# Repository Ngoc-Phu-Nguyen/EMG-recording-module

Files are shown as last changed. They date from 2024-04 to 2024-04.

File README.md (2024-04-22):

# EMG-recording-module
Design for the hardware of EMG recording module  and 3D with cases||
Code for system: STM8S, bluetooth HC-05, EMG recording module || 
# Hardware of EMG recording module
The module use a system filter that enough to clean the signal input before going to ADC. The ADC have I2C interface and programmable gain. The I2C is useful for multiple devices if necessary, and the programmable gain use for auto adjustment function.


Fig1. Scheme of circuit 




Fig2. 3D view of circuit




Fig3. 3D view with cases



Fig4. The real one - this module includes two main parts: Transmitter and receiver. The transmitter includes: STM8S, battery, EMG recording and HC-05. The receiver includes: black pill STM32, HC-05. 



Fig 5. Result of signal EMG from the module - Signal is quite clean. There is almost no noise and interference. The sampling rate of signal is 3ms.

# Coding
Using the tool ST Visual Develop to program and debug for STM8S: setup: CLK, peripheral - I2C, UART,...

Using Arduino and tool Arduino IDE to program for HC-05 (AT command)

Using tool STM32CubeIDE to program and debug for SMT32: peripheral UART

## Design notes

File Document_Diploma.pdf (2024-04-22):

1

Министерство науки и высшего образования Российской Федерации Федеральное государственное автономное образовательное учреждение высшего образования
«Национальный исследовательский Томский политехнический университет»
Школа / филиал | ИШНКБ
Обеспечивающее подразделение | Отделение электронной инженерии
Направление подготовки / специальность | 12.03.04 Биотехнические системы и технологии
Образовательная программа (направленность (профиль)) | Биотехнические системы технологии

ОТЧЕТ

ПО УЧЕБНО-ИССЛЕДОВАТЕЛЬСКОЙ РАБОТЕ

Тема | Разработка автоматического усилителя модуля регистрации ЭМГ
Выполнил обучающийся | Нгуен.Н.Ф
Группа | 1Д01

_____________________

(Подпись обучающегося)

Дата сдачи работы «___» __________ 2024 г.

Проверил науч. руководитель _____________________________________________________

(Степень, звание, должность) | (Ф.И.О.)

Дата проверки____ __________ 2024 г.

Баллы (из 40) ___________

Допустить/не допустить к защите,

Подпись ___________
Отчет принял¹
________________________________________________________________
(Степень, звание, должность) | (Ф.И.О.)
Дата защиты _____ __________ 2024г.
Баллы (из 60) | ___________
Подпись | ___________

Итоговое решение: зачет/незачет, итоговые баллы (из 100) _________________

Томск 2024

1 Председатель комиссии по защите УИРС – руководитель ООП

2

УТВЕРЖДАЮ

Руководитель ООП

__________Е.Ю. Дикман

«___»_________2024 г.

ИНДИВИДУАЛЬНОЕ ЗАДАНИЕ

На учебно-исследовательскую работу

Тема учебно-исследовательской работы:

Разработка автоматического усилителя модуля регистрации ЭМГ

Перечень работ (заданий), подлежащих выполнению:

1. Разработка структурной схемы устройства
2. Разработка принципиальной схемы плата модуля регистрации ЭМГ
3. Разработка программы для микроконтроллера
4. Экспериментальные результаты

Научный руководитель

_____________________________________________ ____________________
(Должность) | (подпись) | (Ф. И. О.)

Задание принял к исполнению _____________ _________________________

(Подпись) | (Ф. И. О. обучающегося)
«___» _________ 2024

3

Оглавление

Разработка принципиальной схемы плата модуля регистрации ЭМГ....... 7

4

Введение

Разрабатываемое устройство главным образом направлено на

использование в сборе данных ЭМГ верхней конечности с целью

использования его для управления протезом руки.

Верхняя конечность включает в себя различные группы мышц, каждая

из которых проявляет различный диапазон амплитуды в сигналах

электромиографии (ЭМГ). Вместо использования ручной калибровки

усиления усилителя или фиксированного уровня усиления автоматическая

система регулировки усиления предоставляет более точное и практичное

решение для захвата различных диапазонов ЭМГ, характерных для различных

групп мышц. Этот автоматизированный подход не только повышает точность

мониторинга | активности | мышц, | но | также | обладает | значительной

универсальностью в многочисленных областях применения, включая

управление протезами. Возможность динамически адаптировать уровень

усиления сенсора для соответствия конкретным характеристикам ЭМГ

различных мышечных групп не только обеспечивает более точный сбор

данных, но также открывает перспективы для передовых приложений в

области протезирования, где точное и отзывчивое управление играет

ключевую | роль | в | улучшении | функциональности | и | интеграции

протезированных конечностей.

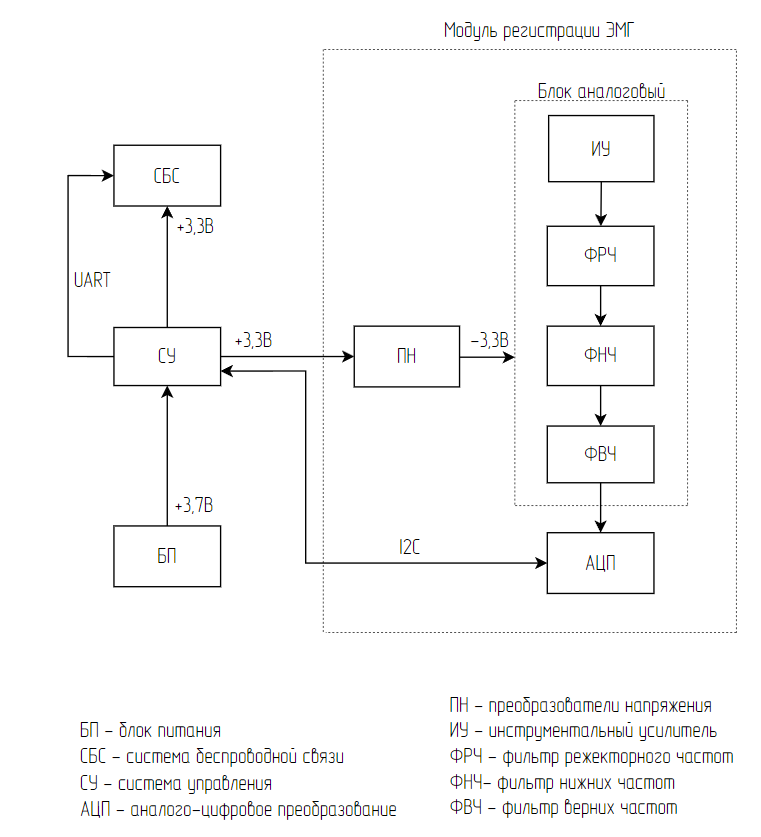
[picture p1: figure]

5

Разработка структурной схемы устройства

На | рисунке | 1 | представлена | структурная | схема | устройства

автоматического усилителя модуля регистрации электромиографии (ЭМГ).

Рисунок 1 – Структурная схема

6

Блок питания (БП) обеспечивает требуемым напряжением каждый

элемент схемы. В качестве источника будут выступать Li-ion аккумулятор. Для

стабилизации | и | получения | необходимого | напряжения | используется

преобразователя постоянного напряжения на 3.3 В.

Система управления (СУ) – обеспечивает взаимодействие и управление

всех | блоков, | устройства. | Для | реализации | данной | системы | будет

использоваться МК STM8S 103F3P6. Поскольку он оснащен необходимыми

интерфейсами: UART, I2C; достаточным количеством памяти и частоты.

Задача СУ будет заключаться в приеме и обработке данных от модуля

регистраиции ЭМГ , последующей отправки этих данных через СБС.

Система беспроводной связи (СБС) – беспроводная связь будет

обеспечивать контакт устройства с принимающей стороной (протезом,

ноутбуком…) для передачи данных. Будет использоваться модуль Bluetooth

HC-05, который простой в использовании, предназначенный для прозрачной

настройки беспроводного соединения. Из СУ будут передаваться собранные

данные от АЦП в СБС и отправляться принимающей стороне.

Регистрация модуля ЭМГ включает: ПН - Преобразователи напряжение

будет | подавать | отрицательное | напряжение | на | усилители. | ИН | -

Инструментальный усилитель будет принимать дифференциальный сигнал от

электрода и эффективно подавлять общий сигнал. Система фильтров включает

в себя ФРЧ - фильтр режекторного частот , ФНЧ - фильтр нижних частот, ФВЧ

- фильтр верних частот. Эти фильтры хорошо удаляют почти весь шум и

помехи. Кстати, через все фильтры сигнал будет усилен настолько, что его

можно | будет | прочитать. | АЦП | - | аналого-цифровое | преобразование

используется для преобразования аналогового сигнала в цифровой сигнал, и с

помощью интерфейса I2C MК может считывать этот цифровой сигнал.

7

Разработка принципиальной схемы плата модуля регистрации

ЭМГ

Инстументальный усилитель AD8221

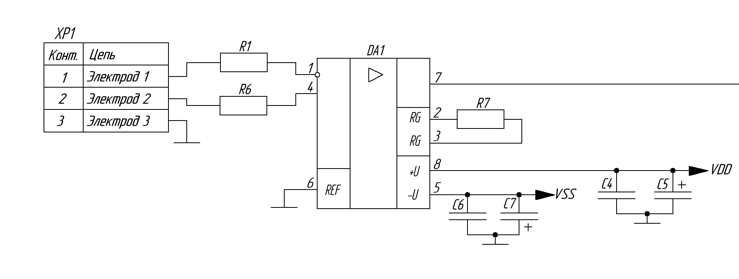
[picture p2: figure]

Рисунок 2 – Схема инструментального усилителя

Данный инструментальный усилитель питается он напряжения ±3.3 В,

для сглаживания более высокочастотных помех применяются конденсаторы

более низкой емкости С4, С5, С6, С7. Конденсатор керамический емкостью 0,1

мкФ (С4, С6) следует разместить рядом с каждым контактом питания,

танталовый конденсатор емкостью 10 мкФ (С5, С7) можно использовать

дальше от детали[1].

Резистор R1, R6 используется для ограничения тока при наличии

напряжения ESD. Следовательно, все компоненты будут защищены от

высотких тока.

Системый фильтр

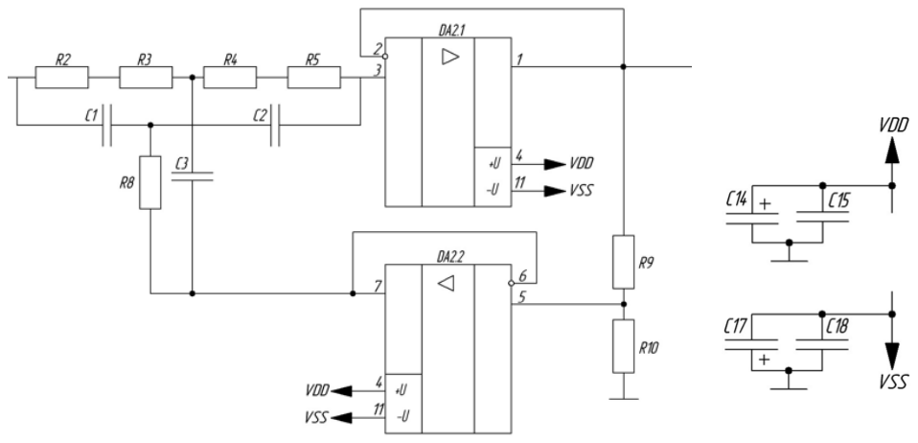
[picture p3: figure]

Рисунок 3 – Фильтр режекторного частот

8

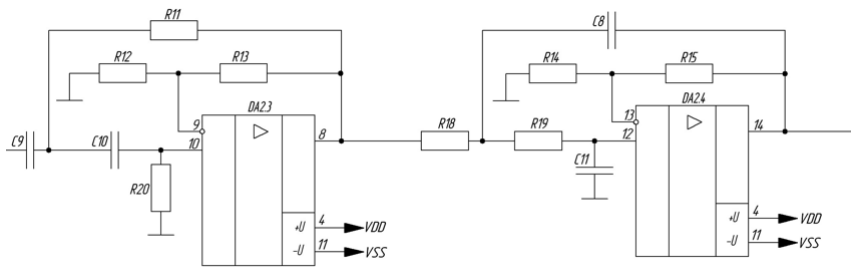
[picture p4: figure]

Рисунок 4 – Фильтр нижник и верних частот

Данные операционные усилители питаются он напряжения ±3.3 В, для

сглаживания более высокочастотных помех применяются конденсаторы более

низкой емкости С14, С15, С17, С18. Конденсатор керамический емкостью 0,1

мкФ (С15, С18) следует разместить рядом с каждым контактом питания,

танталовый конденсатор емкостью 2,2 мкФ (С14, С77) можно использовать

дальше от детали.

Преобразователи напряжения

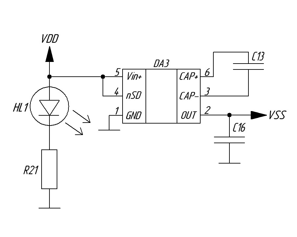
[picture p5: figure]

Рисунок 5 – Схема преобразователя напряжения

Чтобы | максимизировать | эффективность, | уменьшить | падение

выходного напряжения и пульсации напряжения[2], был использованы два

конденсатора Murata 10 мкФ с низким ESR.

Для индикации статуса получаемых напряжения используется

светодиод HL1 с ток ограничительным резистором (R21).

9

Аналого-цифровое преобразование

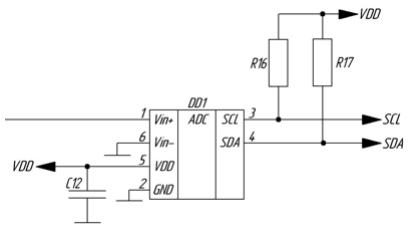
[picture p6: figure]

Рисунок 6 – Схема АЦП

Данный АЦП питается он напряжения 3.3 В, для сглаживания более

высокочастотных помех применяются керамический конденсатор более

низкой емкости С12. Конденсатор следует размещать как можно ближе к

выводу VDD (в пределах одного дюйма). Если схема приложения имеет

отдельные цифровые и аналоговые источники питания, VDD и VSS устройства

MCP3421 должны находиться в аналоговой плоскости [3].

Выводы SCL и SDA MCP3421 имеют конфигурации с открытым

стоком. Для этих контактов требуется подтягивающий резистор, как показано

на рисунке 6. Подтягивающий резистор обычно выбирается в диапазоне от 5

кОм до 10 кОм для стандартного и быстрого режимов [3].

Контактные выходы

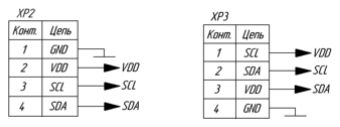
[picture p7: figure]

Рисунок 7 – Схема выходы

Выход предназначен для подключения к MCU через шину I2C, а также

доступен в случае использования нескольких модулей.

10

Разработка моделей печатных плат модуля регистрации ЭМГ

На рисунках 8-9 приводятся результаты разработки платы модуля

регистрации ЭМГ. Плата обеспечена монтажными отверстиями для крепления

её внутри корпуса. На плате имеются два отверстия диаметром 4 мм для пайки

электродами. Расположение | элементов было спроектировано с целью
минимизировать | шум | и | помехи. | Для | достижения | максимальной

эффективности, входной тракт инструментального усилителя выполнен

синхронным. Высокочастотный шум может исходить от цифровой части.

Поэтому аналоговая часть отделена от цифровой. Линия вывода сигнала

изолирована небольшими отверстиями, что гарантирует отсутствие помех.

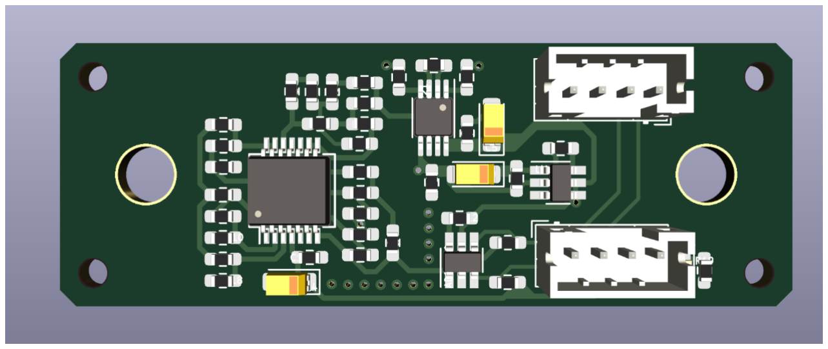
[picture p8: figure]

Рисунок 8 – Вид на верхнюю сторону платы

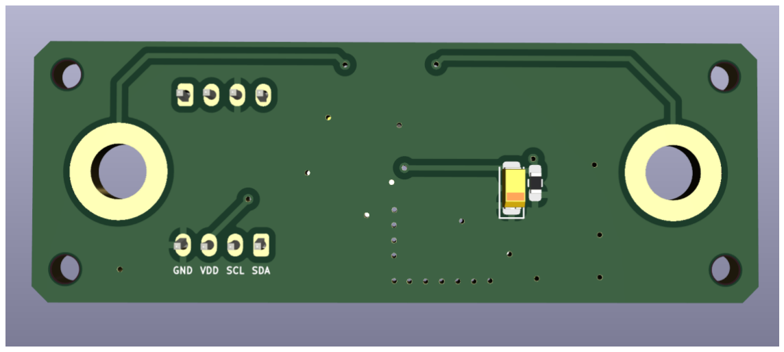
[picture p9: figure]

Рисунок 9 – Вид на нижнюю сторону платы

11

Разработка программы для микроконтроллер

Разработка библиотеки кода и I2C для MCP3421.

Конфигурация АЦП MCP3421 представлена на рисунке 10.

Библиотечный код для MCP3421 был написан на основе его конфигурации.

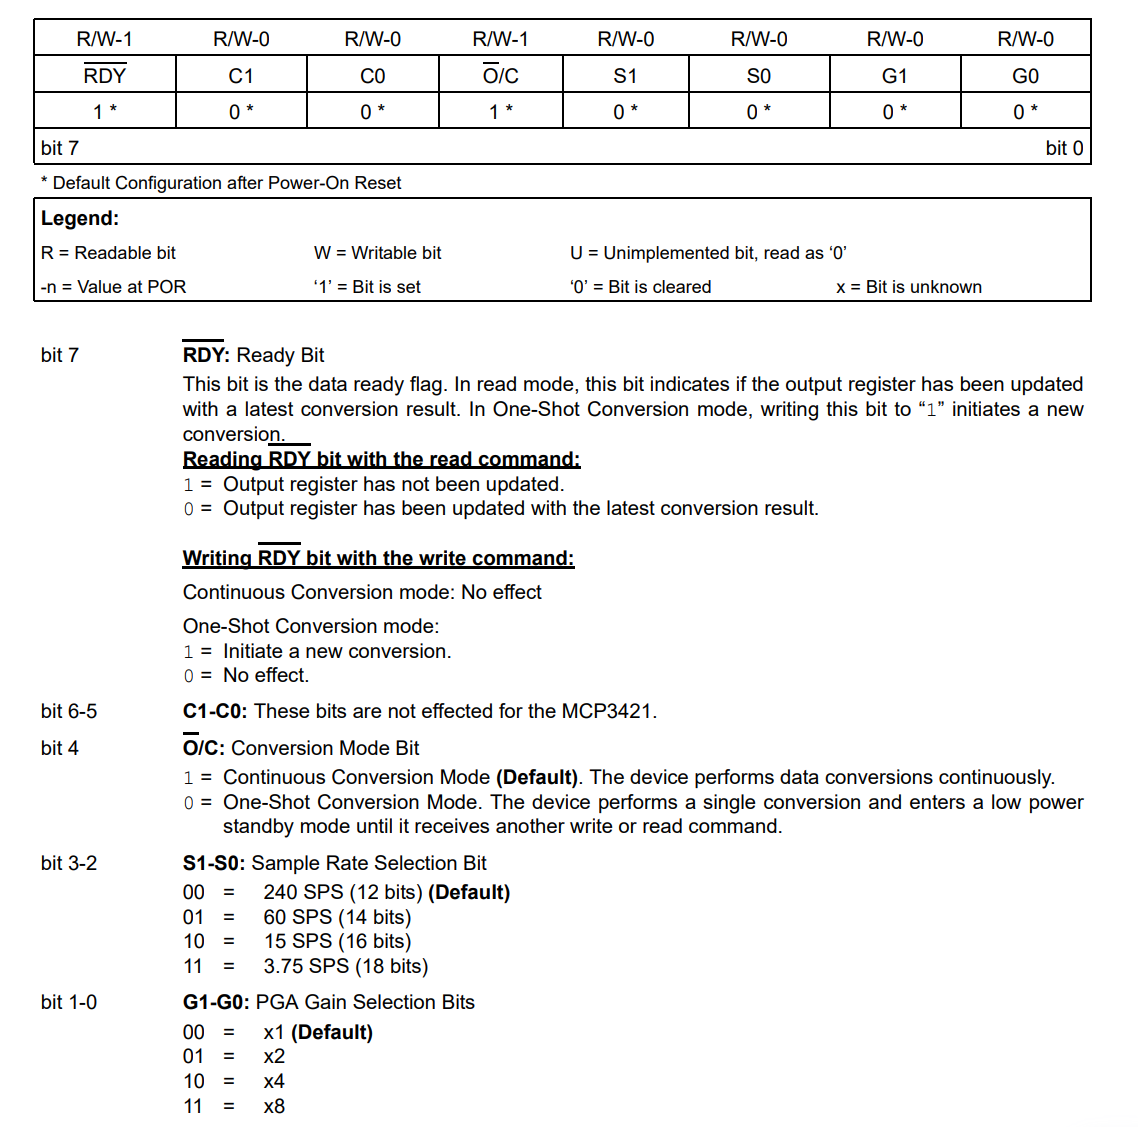
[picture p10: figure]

Рисунок 10 – Конфигурационный байт MPC3421

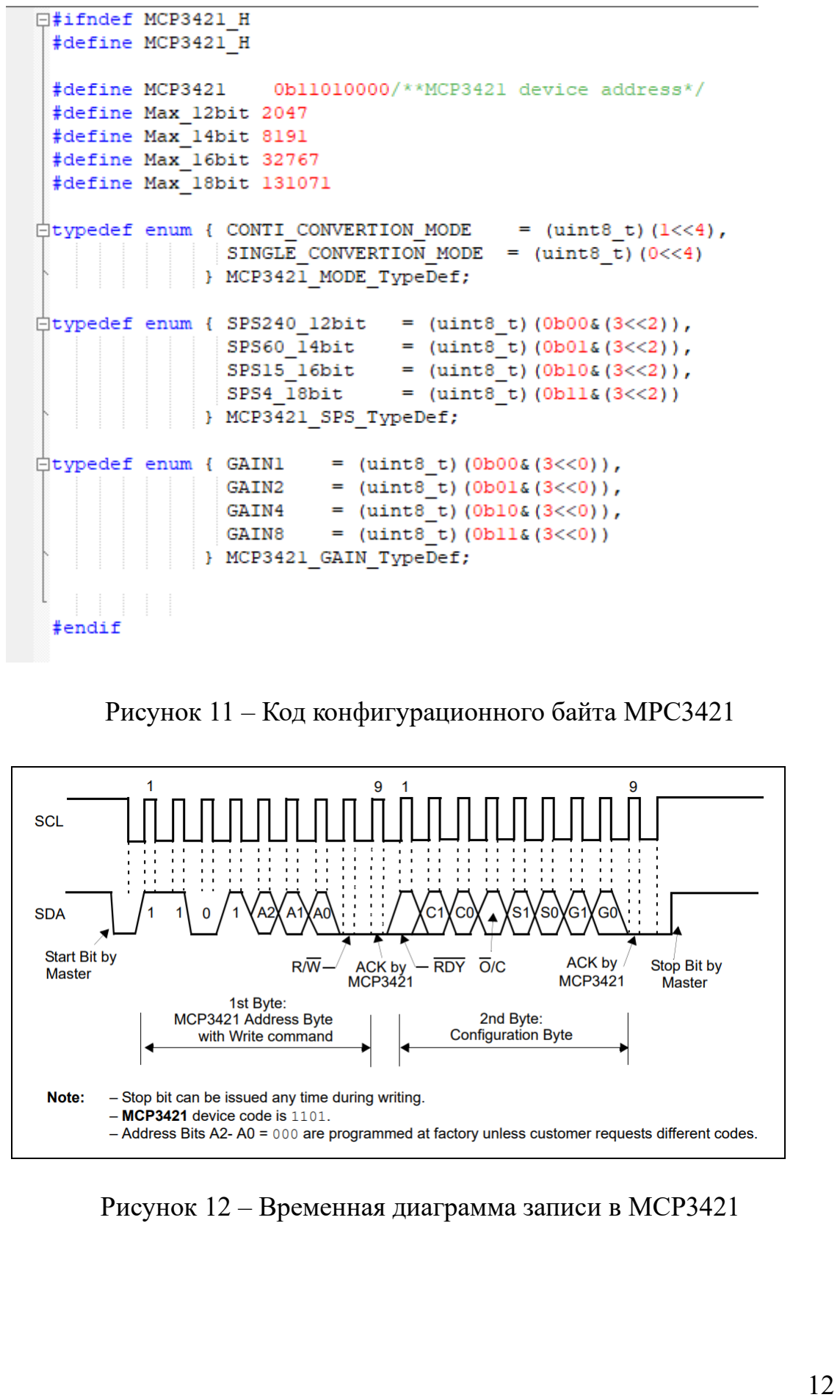
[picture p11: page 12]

12

Рисунок 11 – Код конфигурационного байта MPC3421

Рисунок 12 – Временная диаграмма записи в MCP3421

13

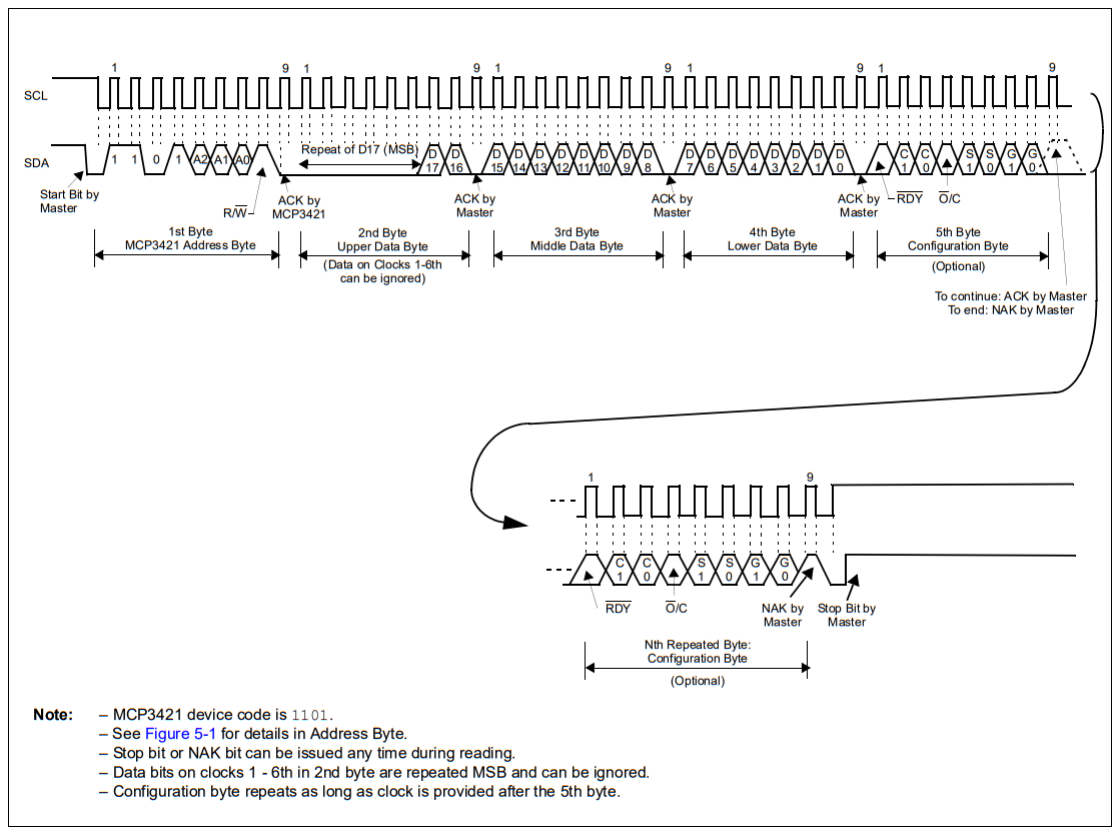
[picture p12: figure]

Рисунок 12 – Временная диаграмма чтения с MCP3421

Настройка для интерфейса I2C - это первый шаг, который должен быть

выполнен. Затем I2C запускается через бит START. Обратите внимание, что

также должен быть установлен бит ACK. Прерывание будет выполнено

немедленно, когда I2C запускается и устанавливается флаг SB. Внутри

обработчика прерываний первым делом отправляется адрес ведомого

устройства, чтобы проверить, совпадает ли он или нет. Если адрес совпадает,

процесс прерывания повторяется, поскольку установлен флаг ADDR. Затем

проверяется флаг TRA, чтобы определить, будет ли I2C в режиме чтения или

записи. В каждом режиме соответственно считывается или записывается

регистр DR. В конце процесса чтения или записи должен быть установлен бит

STOP, чтобы освободить шину перед переходом к новому общению.

На основе функционального описания I2C в таблице данных STM8S[5]

и временной диаграммы чтения/записи MCP3421 (рисунок 11,12) было

написано краткое описание, которое также используется для алгоритма

(рисунок 13).

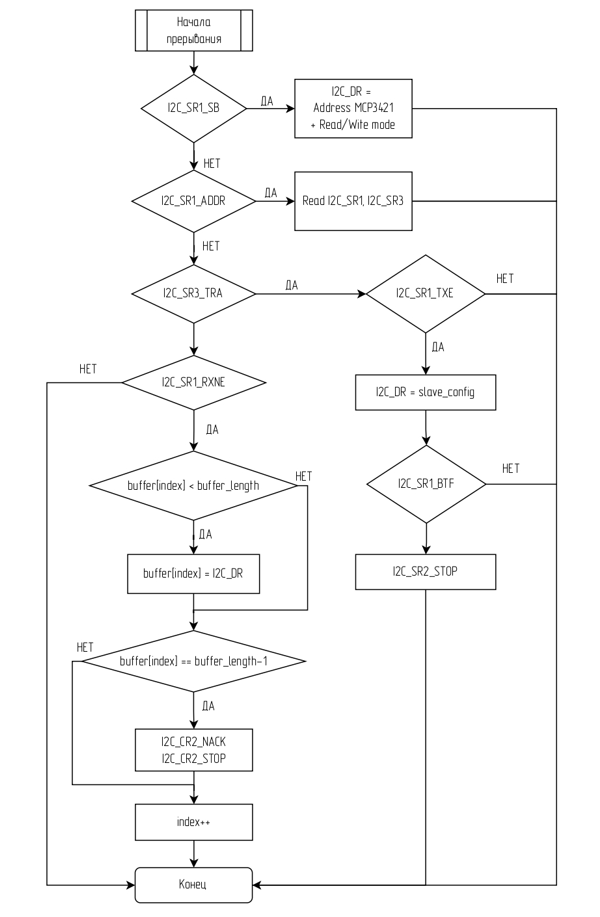
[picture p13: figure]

14

Рисунок 13 – Алгоритм прерывания I2C STM8S

15

Настройка для HC-05

Для взаимодействия с HC05-модулем используются AT-команды.

Интерфейсом для взаимодействия служит UART. Первоначальные настройки

HC05 модуля заключались в следующем [4]:

− Тестовая команда: AT

− Проверить адрес AT+ADDR

− Настроить UART(baud rate, stop bit, parity): AT+UART=9600,1,0

− Установить/проверить режим модуля (master): AT+ROLE=1

− Установить/проверить режим подключения (фиксированный адрес):

AT+CMODE=0

− Подключиться к подчиненному устройству: AT+BIND=xxxx,xx,xxxxxx

Чтобы включить режим AT для модуля HC-05, подключите вывод PIO11

к высокому уровню, используя скорость передачи данных 34800. Пример

показан на рисунке xx ниже.

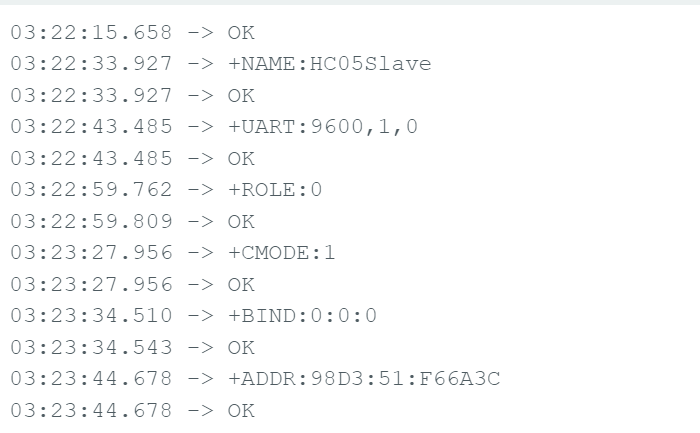
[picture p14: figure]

Рисунок 14 – Ответ от HC05 при использовании AT-команды

16

Фунция автоматического усиления

Как только значение будет получено от АЦП, будет запущен процесс

проверки, чтобы убедиться, что значение все еще находится в пределах

диапазона. Если выход за пределы диапазона достигнут, коэффициент

усиления АЦП снижается. Этот процесс повторяется до тех пор, пока не будет

достигнут минимальный коэффициент усиления. Алгоритм всей программы

показан на рисунке 15 ниже. Код программы указан в приложении Е.

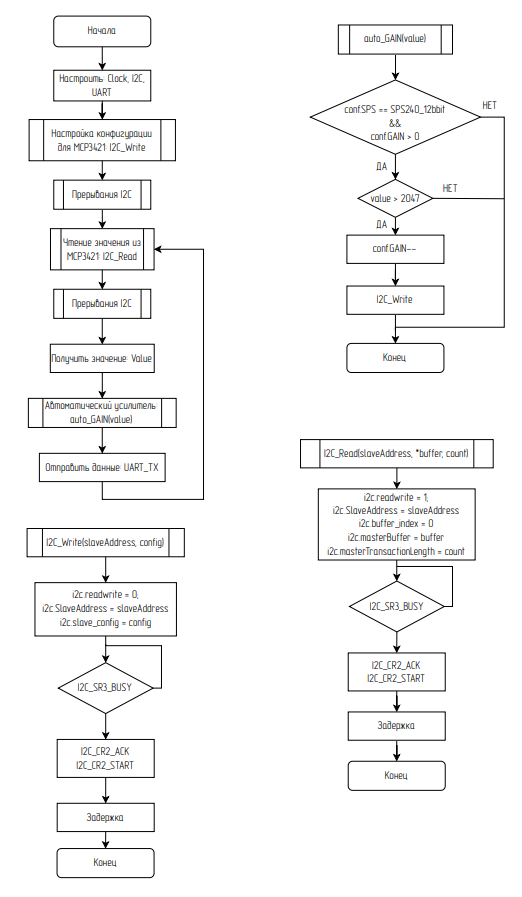
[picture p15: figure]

Рисунок 15 – Алгоритм всей программы

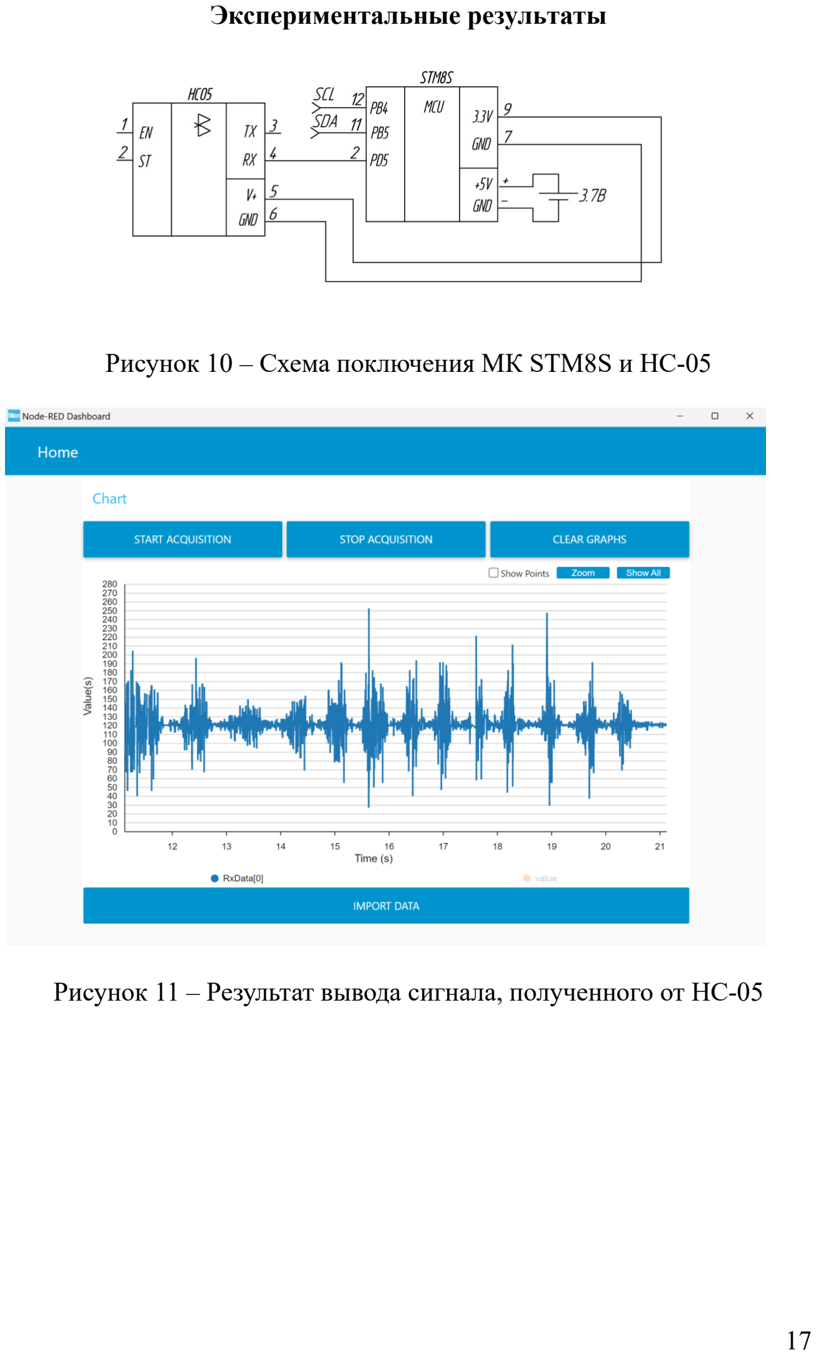
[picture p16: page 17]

17

Экспериментальные результаты

Рисунок 10 – Схема поключения МК STM8S и HC-05

Рисунок 11 – Результат вывода сигнала, полученного от HC-05

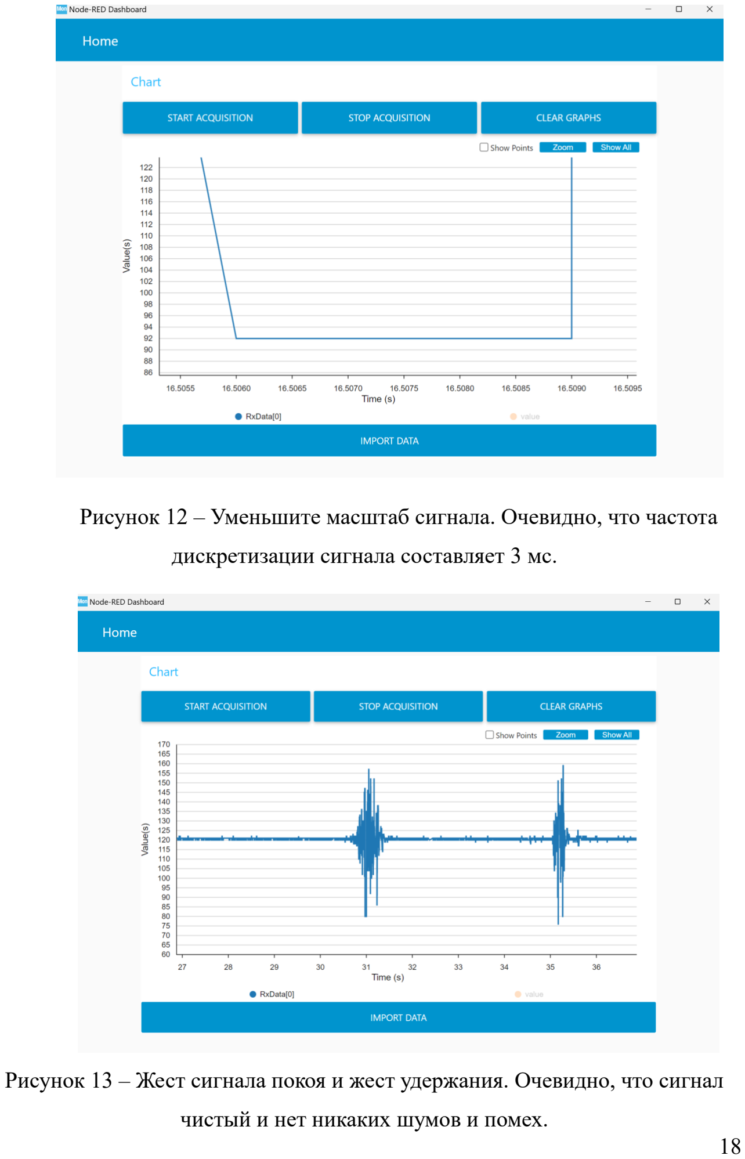
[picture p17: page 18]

18

Рисунок 12 – Уменьшите масштаб сигнала. Очевидно, что частота

дискретизации сигнала составляет 3 мс.

Рисунок 13 – Жест сигнала покоя и жест удержания. Очевидно, что сигнал

чистый и нет никаких шумов и помех.

19

Список литературы

1. Datasheet – AD8221, Инструментальный усилитель, [Электронный

ресурс] – Режим доступа: https://www.analog.com/media/en/technical-

documentation/data-sheets/ad8221.pdf (Дата обращения: 07.04.2024)

2. Datasheet – LM2664, Преобразователь напряжения с переключаемым
конденсатором, | [Электронный | ресурс] | – | Режим | доступа:

https://www.ti.com/lit/ds/symlink/lm2664.pdf?ts=1713246289404

(Дата обращения: 07.04.2024)

3. Datasheet – MCP3421, Цировный потенциометр, [Электронный

ресурс] – Режим доступа: https://www.analog.com/media/en/technical-

documentation/data-sheets/ad5259.pdf (https://www.analog.com/media/en/technical-documentation/data-sheets/ad5259.pdf) (Дата обращения: 07.04.2024)

4. Datasheet – HC-05, Модуль Bluetooth для последовательного порта,
[Электронный | ресурс] | – | Режим | доступа:

https://components101.com/sites/default/files/component_datasheet/HC

-05%20Datasheet.pdf ( Дата обращения: 07.04.2024)

5. Reference manual – STM8S Series and STM8AF Series 8-bit
microcontroller, | [Электронный | ресурс] | – | Режим | доступа:
https://www.st.com/content/st_com/en.html | (Дата | обращения:

07.04.2024)

20

Приложение А

Модуль регистрации ЭМГ

Спецификация

ФЮРА.942519.001

21

Приложение Б

Модуль регистрации ЭМГ

Схема электрическая принципиальная

ФЮРА.942519.001 ПЭ3

22

Приложение В

Модуль регистрации ЭМГ

Сборочный чертеж платы

ФЮРА.942519.002.СБ

23

Приложение Г

Модуль регистрации ЭМГ

Печатная плата

ФЮРА.942519.003

24

Приложение Д

Модуль регистрации ЭМГ

Перечень элементов

ФЮРА.942519.004 ПЭ

25

Приложение Е

Модуль регистрации ЭМГ

Код микроконтроллера

Код main.c

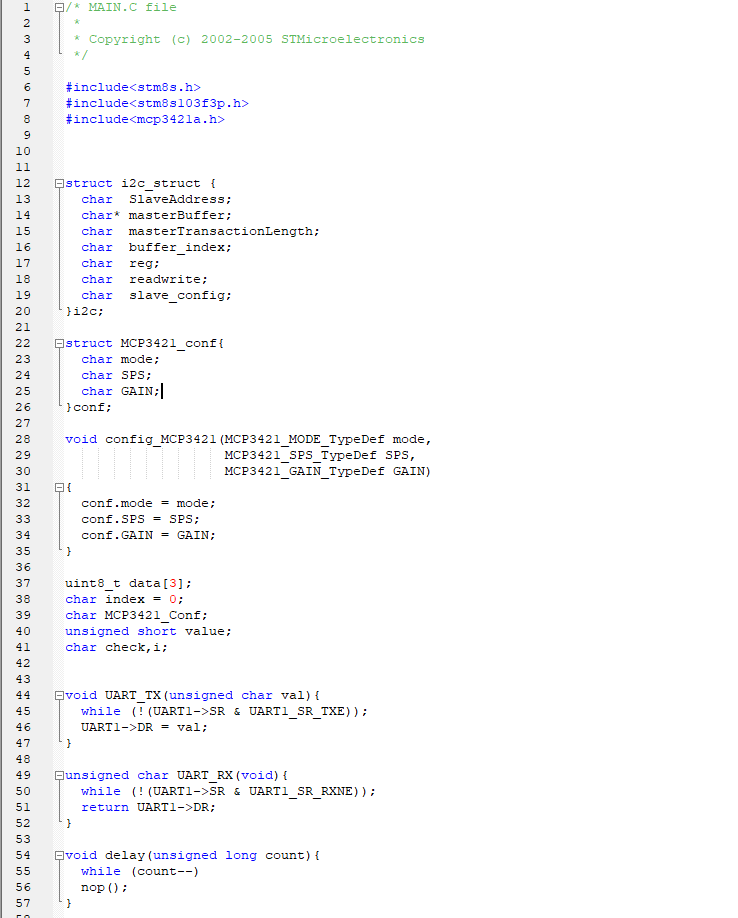
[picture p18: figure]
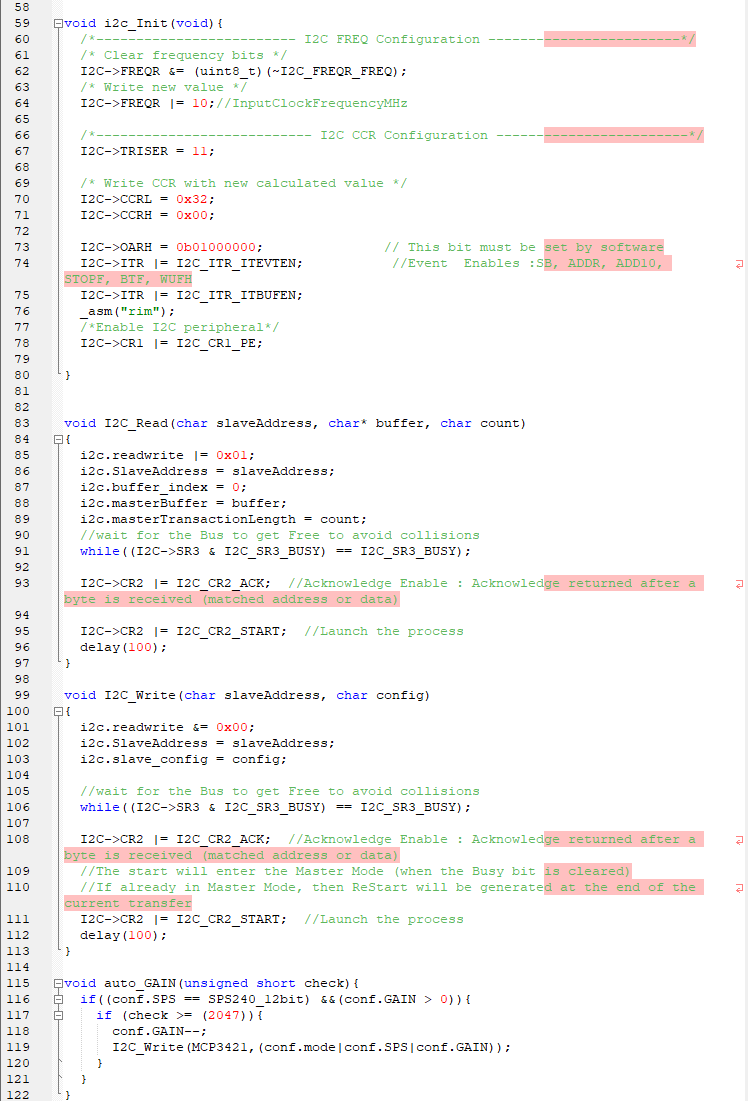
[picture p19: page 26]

26

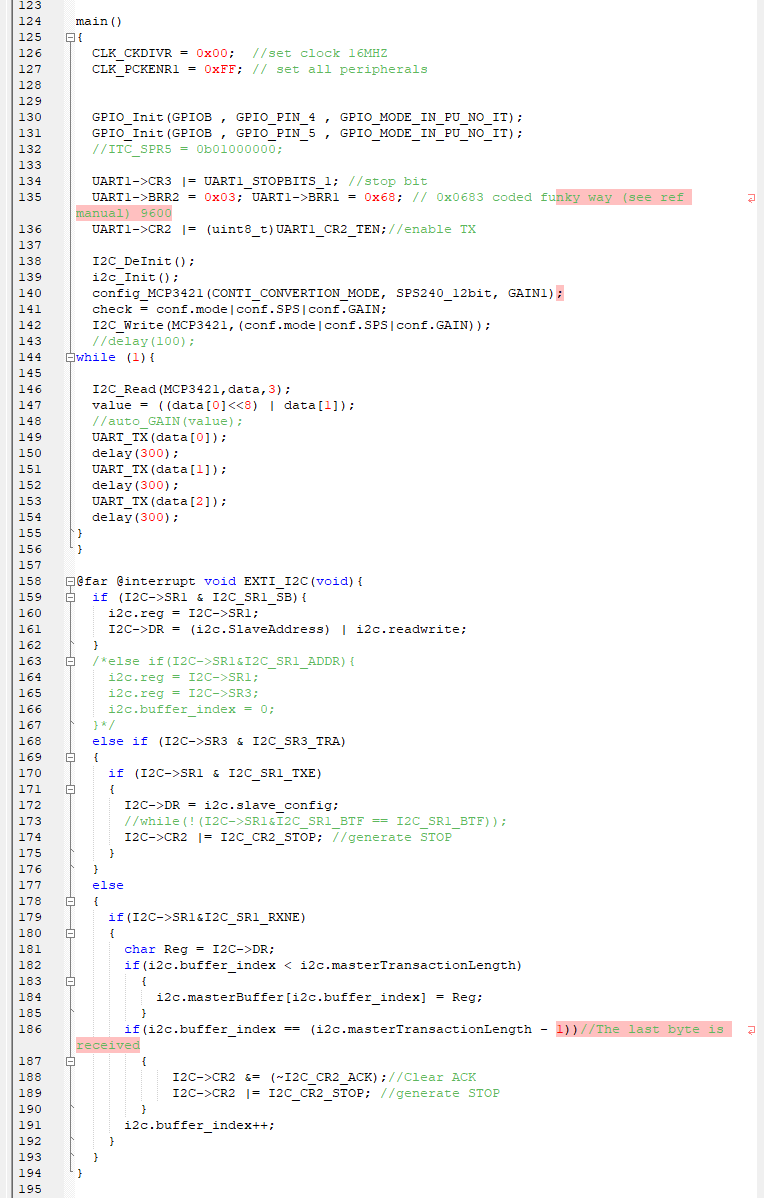
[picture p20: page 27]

27

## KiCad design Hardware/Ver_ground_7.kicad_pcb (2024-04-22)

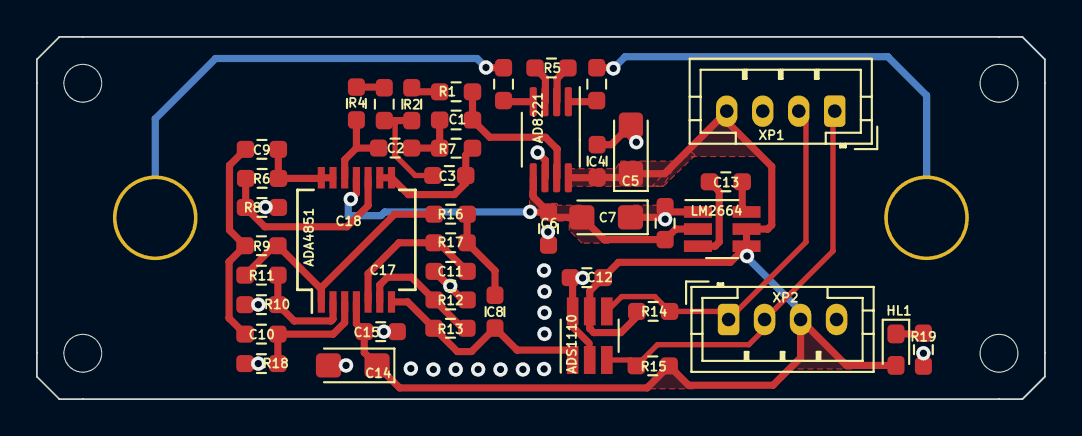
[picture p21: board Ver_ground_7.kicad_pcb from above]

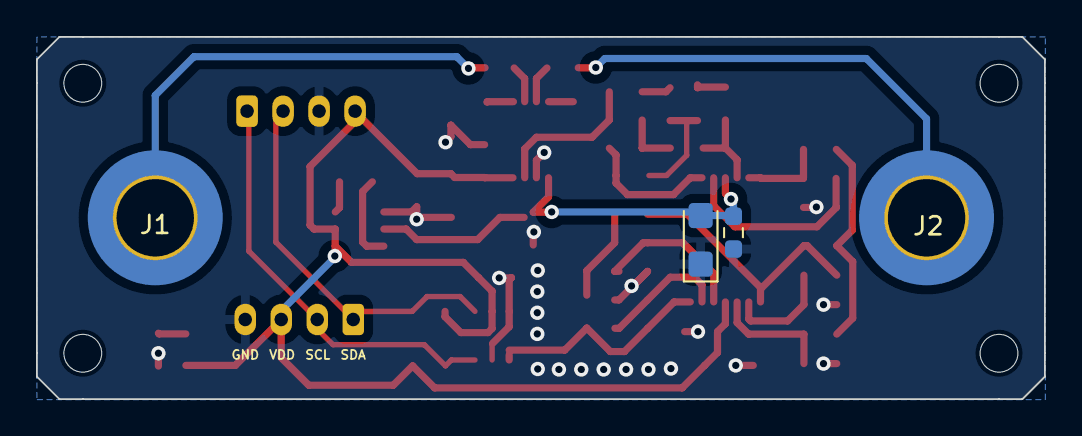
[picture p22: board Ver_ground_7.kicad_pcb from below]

Board: 2 copper layers, 56.0 x 20.1 mm, 52 parts (4 on the bottom side), 31 nets.

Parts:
C1, C2, C4, C6, C12: 0.1u; R_0603_1608Metric_Pad0.98x0.95mm_HandSolder
C3: 0.2u; R_0603_1608Metric_Pad0.98x0.95mm_HandSolder
C5, C7: 10u; CP_EIA-3216-18_Kemet-A
C8, C11: 3300p; R_0603_1608Metric_Pad0.98x0.95mm_HandSolder
C9, C10: 1u; R_0603_1608Metric_Pad0.98x0.95mm_HandSolder
C13, C16: 10u; R_0603_1608Metric_Pad0.98x0.95mm_HandSolder
C14, C17: 2.2u; CP_EIA-3216-18_Kemet-A
C15, C18: 0.01u; R_0603_1608Metric_Pad0.98x0.95mm_HandSolder
H1, H2, H3, H4: MountingHole; MountingHole_2.1mm
J1, J2: Conn_01x01_Pin; MountingHole_4.3mm_M4_DIN965_Pad_TopOnly
J3, J4: Conn_01x04_Pin; JST_PH_B4B-PH-K_1x04_P2.00mm_Vertical
LED1: IR26-21C_L110_TR8; LED_0603_1608Metric_Pad1.05x0.95mm_HandSolder
R1, R2, R3, R4, R7, R9, R18: 16k; R_0603_1608Metric_Pad0.98x0.95mm_HandSolder
R5, R6, R19: 1k; R_0603_1608Metric_Pad0.98x0.95mm_HandSolder
R8: 3.9k; R_0603_1608Metric_Pad0.98x0.95mm_HandSolder
R10, R12, R14, R15: 10k; R_0603_1608Metric_Pad0.98x0.95mm_HandSolder
R11, R13: 5.6k; R_0603_1608Metric_Pad0.98x0.95mm_HandSolder
R16, R17, R20, R21: 100k; R_0603_1608Metric_Pad0.98x0.95mm_HandSolder
U1: AD8221; MSOP-8_3x3mm_P0.65mm
U2: ADA4851; SSOP-14_5.3x6.2mm_P0.65mm
U3: LM2664; SOT-23-6_Handsoldering
U4: MCP3421; SOT-23-6_Handsoldering

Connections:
GNDA: C4.1, C5.2, C6.2, C7.1, C11.1, C12.1, C14.2, C15.1, C16.1, C17.1, C18.2, J3.3, J4.4, R8.1, R10.1, R12.2, R18.1, R19.1, U1.6 (Ref), U3.1 (GND), U4.2 (GND), U4.6 (VIN-)
unnamed: C1.1, R1.1, U1.7
unnamed: C1.2, C2.1, R7.2
unnamed: C3.2, R2.1, R3.2
unnamed: C8.2, R16.2, R17.1
unnamed: C9.2, C10.1, R9.1
unnamed: J1.1, R20.1
unnamed: J2.1, R21.1
unnamed: LED1.1 (K), R19.2
unnamed: R1.2, R2.2
unnamed: R3.1, R4.1
unnamed: R5.1, U1.2 (Rg)
unnamed: R5.2, U1.3 (Rg)
unnamed: R9.2, R11.2, R16.1, U2.1
unnamed: R21.2, U1.4 (+)
unnamed: R20.2, U1.1 (-)
unnamed: C10.2, R18.2, U2.3 (+)
unnamed: R10.2, R11.1, U2.2 (-)
unnamed: C11.2, R17.2, U2.5 (+)
unnamed: R12.1, R13.1, U2.6 (-)
unnamed: R6.1, R8.2, U2.10 (+)
unnamed: C3.1, R7.1, U2.8, U2.9 (-)
unnamed: C2.2, R4.2, U2.12 (+)
unnamed: C9.1, R6.2, U2.13 (-), U2.14
unnamed: C13.1, U3.6 (CAP+)
unnamed: C13.2, U3.3 (CAP-)
Out: C8.1, R13.2, U2.7, U4.1 (VIN+)
SCL: J3.1, J4.2, R15.1, U4.3 (SCL)
SDA: J3.2, J4.1, R14.1, U4.4 (SDA)
VDDA: C4.2, C5.1, C12.2, C14.1, C15.2, J3.4, J4.3, LED1.2 (A), R14.2, R15.2, U1.8 (Vs+), U2.4 (V+), U3.4 (nSD), U3.5 (V+), U4.5 (VDD)
VSSA: C6.1, C7.2, C16.2, C17.2, C18.1, U1.5 (Vs-), U2.11 (V-), U3.2 (OUT)

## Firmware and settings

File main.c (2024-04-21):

/* MAIN.C file
 * 
 * Copyright (c) 2002-2005 STMicroelectronics
 */

#include<stm8s.h>
#include<stm8s103f3p.h>
#include<mcp3421a.h>



struct i2c_struct {
	char	SlaveAddress;
	char*	masterBuffer;
	char	masterTransactionLength;
	char	buffer_index;
	char  reg;
	char	readwrite;
	char  slave_config;
}i2c;

struct MCP3421_conf{
	char mode;
	char SPS;
	char GAIN;
}conf;

void config_MCP3421(MCP3421_MODE_TypeDef mode,
										MCP3421_SPS_TypeDef SPS, 
										MCP3421_GAIN_TypeDef GAIN)
{
	conf.mode = mode;
	conf.SPS = SPS;
	conf.GAIN = GAIN;
}

uint8_t data[3];
char index = 0;
char MCP3421_Conf;
unsigned short value;
char check,i;


void UART_TX(unsigned char val){
	while (!(UART1->SR & UART1_SR_TXE));
	UART1->DR = val;
}

unsigned char UART_RX(void){
	while (!(UART1->SR & UART1_SR_RXNE));
	return UART1->DR;
}

void delay(unsigned long count){
	while (count--)
	nop();
}

void i2c_Init(void){
  /*------------------------- I2C FREQ Configuration ------------------------*/
  /* Clear frequency bits */
  I2C->FREQR &= (uint8_t)(~I2C_FREQR_FREQ);
  /* Write new value */
  I2C->FREQR |= 10;//InputClockFrequencyMHz
	
  /*--------------------------- I2C CCR Configuration ------------------------*/
	I2C->TRISER = 11;

	/* Write CCR with new calculated value */
  I2C->CCRL = 0x32;
  I2C->CCRH = 0x00;
	
	I2C->OARH = 0b01000000;               // This bit must be set by software
	I2C->ITR |= I2C_ITR_ITEVTEN;           //Event  Enables :SB, ADDR, ADD10, STOPF, BTF, WUFH
	I2C->ITR |= I2C_ITR_ITBUFEN; 
	_asm("rim");
	/*Enable I2C peripheral*/
	I2C->CR1 |= I2C_CR1_PE;
	
}


void I2C_Read(char slaveAddress, char* buffer, char count)
{
	i2c.readwrite |= 0x01;
	i2c.SlaveAddress = slaveAddress;
	i2c.buffer_index = 0;
	i2c.masterBuffer = buffer;
	i2c.masterTransactionLength = count;	
	//wait for the Bus to get Free to avoid collisions
	while((I2C->SR3 & I2C_SR3_BUSY) == I2C_SR3_BUSY);
	
	I2C->CR2 |= I2C_CR2_ACK;	//Acknowledge Enable : Acknowledge returned after a byte is received (matched address or data)

	I2C->CR2 |= I2C_CR2_START;	//Launch the process
	delay(100);
}

void I2C_Write(char slaveAddress, char config)
{
	i2c.readwrite &= 0x00;
	i2c.SlaveAddress = slaveAddress;
	i2c.slave_config = config;
	
	//wait for the Bus to get Free to avoid collisions
	while((I2C->SR3 & I2C_SR3_BUSY) == I2C_SR3_BUSY);
	
	I2C->CR2 |= I2C_CR2_ACK;	//Acknowledge Enable : Acknowledge returned after a byte is received (matched address or data)
	//The start will enter the Master Mode (when the Busy bit is cleared)
	//If already in Master Mode, then ReStart will be generated at the end of the current transfer
	I2C->CR2 |= I2C_CR2_START;	//Launch the process
	delay(100);
}

void auto_GAIN(unsigned short check){
	if((conf.SPS == SPS240_12bit) &&(conf.GAIN > 0)){
		if (check >= (2047)){
			conf.GAIN--;
			I2C_Write(MCP3421,(conf.mode|conf.SPS|conf.GAIN));
		}
	}
}

main()
{
	CLK_CKDIVR = 0x00;  //set clock 16MHZ
	CLK_PCKENR1 = 0xFF; // set all peripherals
	

	GPIO_Init(GPIOB , GPIO_PIN_4 , GPIO_MODE_IN_PU_NO_IT);   
	GPIO_Init(GPIOB , GPIO_PIN_5 , GPIO_MODE_IN_PU_NO_IT);
	//ITC_SPR5 = 0b01000000;
	
	UART1->CR3 |= UART1_STOPBITS_1; //stop bit
	UART1->BRR2 = 0x03; UART1->BRR1 = 0x68; // 0x0683 coded funky way (see ref manual) 9600
	UART1->CR2 |= (uint8_t)UART1_CR2_TEN;//enable TX 
	
	I2C_DeInit();
	i2c_Init();
	config_MCP3421(CONTI_CONVERTION_MODE, SPS240_12bit, GAIN1);
	check = conf.mode|conf.SPS|conf.GAIN;
	I2C_Write(MCP3421,(conf.mode|conf.SPS|conf.GAIN));
	//delay(100);
while (1){
	
	I2C_Read(MCP3421,data,3);
	value = ((data[0]<<8) | data[1]);
	//auto_GAIN(value);
	UART_TX(data[0]);
	delay(300);
	UART_TX(data[1]);
	delay(300);
	UART_TX(data[2]);
	delay(300);
}
}

@far @interrupt void EXTI_I2C(void){
	if (I2C->SR1 & I2C_SR1_SB){
		i2c.reg = I2C->SR1;
		I2C->DR = (i2c.SlaveAddress) | i2c.readwrite;
	}	
	/*else if(I2C->SR1&I2C_SR1_ADDR){
		i2c.reg = I2C->SR1;
		i2c.reg = I2C->SR3;
		i2c.buffer_index = 0;
	}*/
	else if (I2C->SR3 & I2C_SR3_TRA)
	{
		if (I2C->SR1 & I2C_SR1_TXE)
		{
			I2C->DR = i2c.slave_config;
			//while(!(I2C->SR1&I2C_SR1_BTF == I2C_SR1_BTF));
			I2C->CR2 |= I2C_CR2_STOP; //generate STOP
		}
	}
	else 
	{
		if(I2C->SR1&I2C_SR1_RXNE)
		{
			char Reg = I2C->DR;
			if(i2c.buffer_index < i2c.masterTransactionLength)
				{
					i2c.masterBuffer[i2c.buffer_index] = Reg;
				}
			if(i2c.buffer_index == (i2c.masterTransactionLength - 1))//The last byte is received
				{
						I2C->CR2 &= (~I2C_CR2_ACK);//Clear ACK 
						I2C->CR2 |= I2C_CR2_STOP; //generate STOP
				}
			i2c.buffer_index++;
		}
	}
	//change one more time
}

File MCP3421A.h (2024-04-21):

#ifndef MCP3421_H
#define	MCP3421_H

#define MCP3421    0b11010000/**MCP3421 device address*/
#define Max_12bit 2047 
#define Max_14bit 8191
#define Max_16bit 32767
#define Max_18bit 131071

typedef enum { CONTI_CONVERTION_MODE    = (uint8_t)(1<<4), 
               SINGLE_CONVERTION_MODE  = (uint8_t)(0<<4)
             } MCP3421_MODE_TypeDef;

typedef enum { SPS240_12bit   = (uint8_t)(0b00&(3<<2)), 
               SPS60_14bit    = (uint8_t)(0b01&(3<<2)),
               SPS15_16bit    = (uint8_t)(0b10&(3<<2)),
               SPS4_18bit     = (uint8_t)(0b11&(3<<2))
             } MCP3421_SPS_TypeDef;

typedef enum { GAIN1    = (uint8_t)(0b00&(3<<0)), 
               GAIN2    = (uint8_t)(0b01&(3<<0)),
               GAIN4    = (uint8_t)(0b10&(3<<0)),
               GAIN8    = (uint8_t)(0b11&(3<<0))
             } MCP3421_GAIN_TypeDef; 

           
#endif
